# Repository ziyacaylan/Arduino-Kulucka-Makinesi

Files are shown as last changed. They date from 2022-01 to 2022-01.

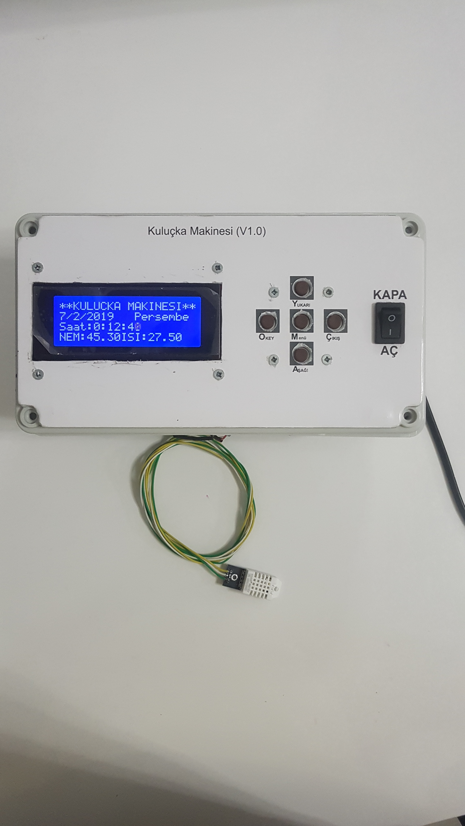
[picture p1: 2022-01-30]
20190207_001548.jpg

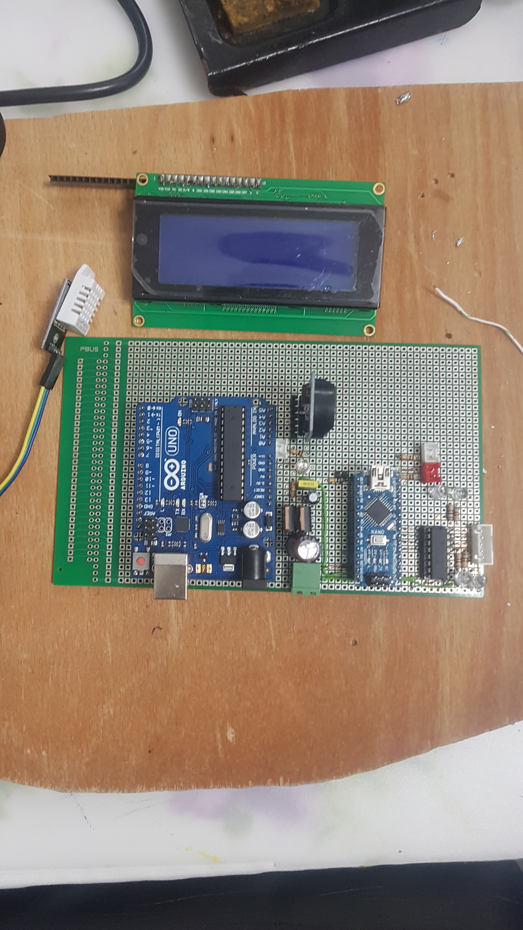
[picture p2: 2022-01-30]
20190119_183852.jpg

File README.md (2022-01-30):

# Arduino-Kulucka-Makinesi
Arduino Uno ile yapilmistir.

Kulucka makinesi 24 lü viyol e sahip, 
program arduino uno kullanılarak hazırlanmıştır. 
Tamamen elimdeki malzemelerden kullanarak tasarladım. 
Sadece saat modili ve sensörleri temin etmiştim. 
Program incelenerek geliştirilebilir yada aynı şekilde kullanılabilir. 
Denemsi yapılmıştır ve başarılı bir civciv çıkımı sağlanmıştır.
Viyol kontraplak kullanılarak yapılmıştır. 
Solidworks çizimleri dosya içerisindedir.
Arduino programı geliştirilebilir.
Viyol motoru olarak elimde step motyor elduğundan ben step motor kullandım ve step motoru ULN2003 entegresi ile sürdüm.
Entegreyide arduino nano vardı fazla elimde onunla programlayıp sürdüm. Arduino uno dan tetik alıp nanoyu sürdüm. 
Sizler elinizdeki malzemelere göre projeyi düzenleyebilirsiniz.

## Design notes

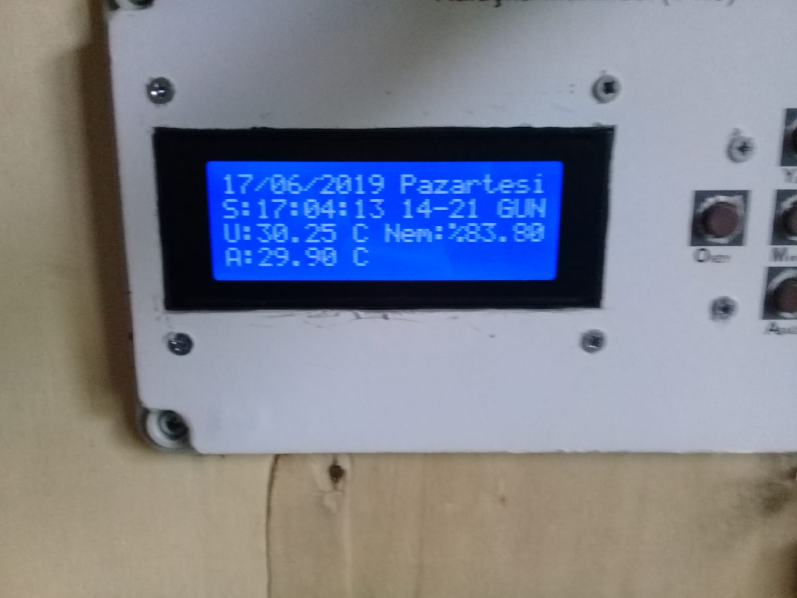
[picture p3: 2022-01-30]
IMG-20190617-WA0002.jpg

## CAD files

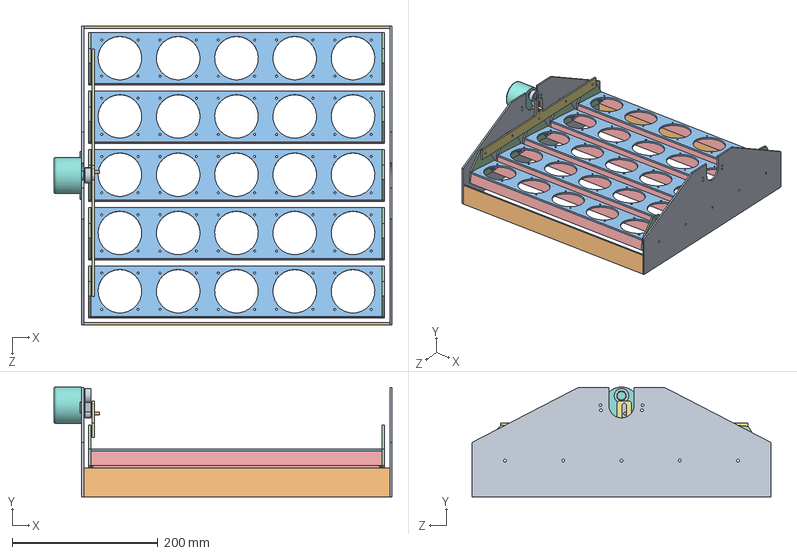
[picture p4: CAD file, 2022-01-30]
Viyol_Solid Design/NEW/montaj.SLDASM
464.0 x 151.0 x 410.0 mm
Kasa_on_arka x 2
Kasa_yan x 2
yiyol x 5
viyol_on_arka x 10
viyol_yan x 10
viyol_destek x 20
Viyol_mafsal
Motor
motor_segman
vida

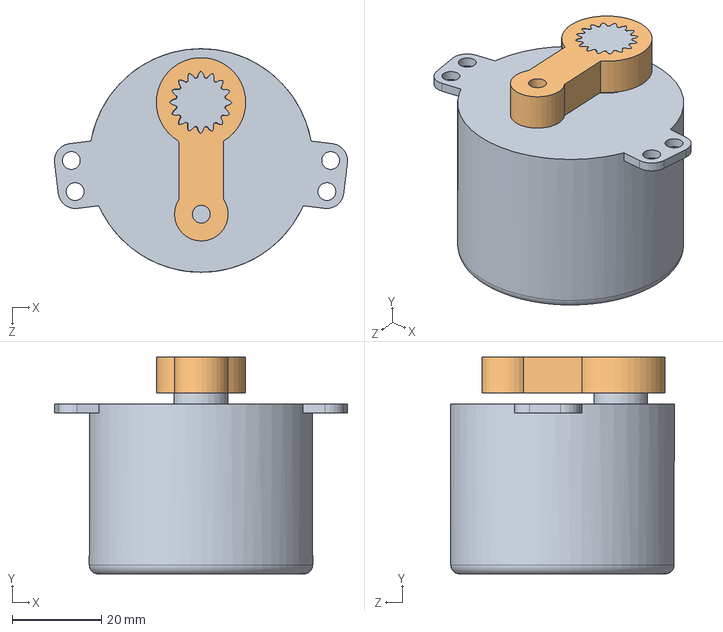
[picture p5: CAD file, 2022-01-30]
Viyol_Solid Design/NEW/motor_montaj.SLDASM
65.5 x 48.5 x 50.0 mm
Motor
motor_segman

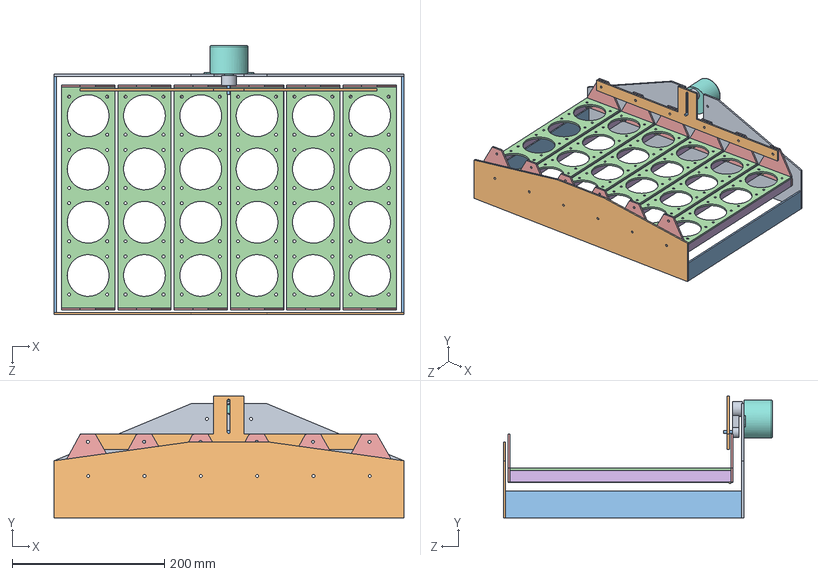
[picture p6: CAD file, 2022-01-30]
Viyol_Solid Design/6lı/montaj.SLDASM
460.0 x 160.0 x 354.0 mm
Kasa_on
Viyol_kasa_arka
Kasa_yanlar x 2
viyol x 6
viyol_on_arka x 12
viyol_yanlar x 12
viyol_destek x 24
Motor
motor_segman
vida

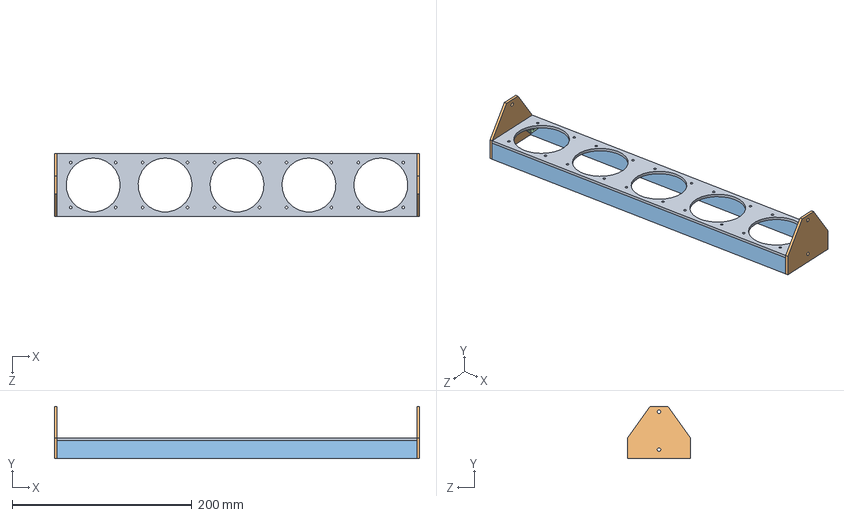
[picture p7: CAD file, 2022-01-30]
Viyol_Solid Design/NEW/viyol.SLDASM
406.0 x 58.0 x 70.0 mm
yiyol
viyol_on_arka x 2
viyol_yan x 2
viyol_destek x 4

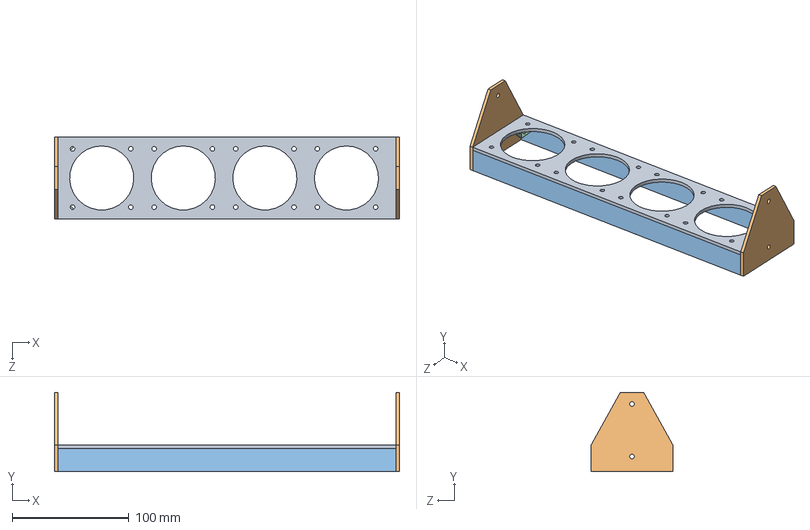
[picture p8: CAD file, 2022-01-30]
Viyol_Solid Design/6lı/viyol_montaj.SLDASM
296.0 x 68.0 x 70.0 mm
viyol
viyol_on_arka x 2
viyol_yanlar x 2
viyol_destek x 4

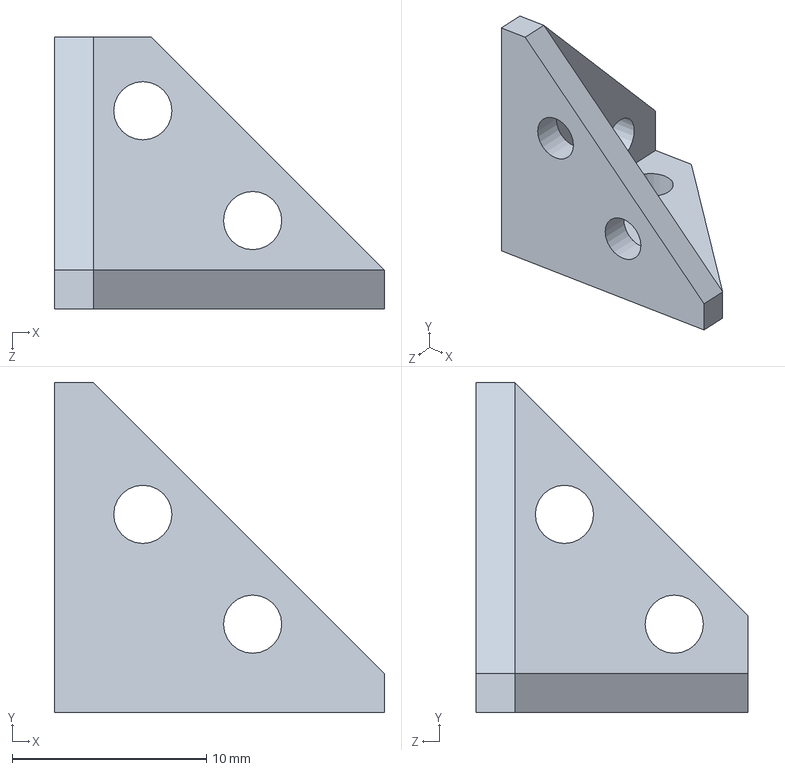
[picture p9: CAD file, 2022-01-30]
Viyol_Solid Design/6lı/viyol_destek.SLDPRT
17.0 x 17.0 x 14.0 mm

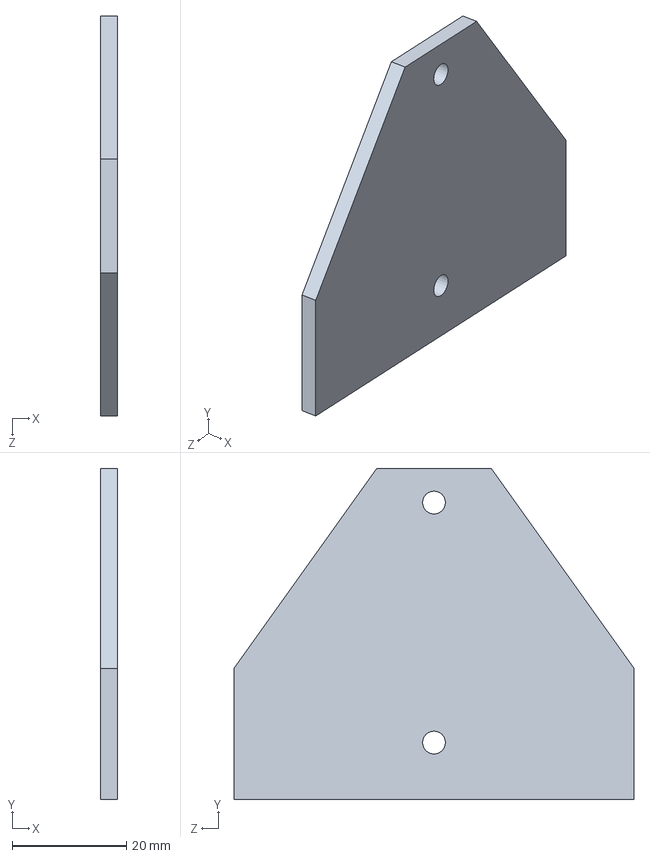
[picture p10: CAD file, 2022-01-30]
Viyol_Solid Design/NEW/viyol_on_arka.SLDPRT
3.00 x 58.0 x 70.0 mm

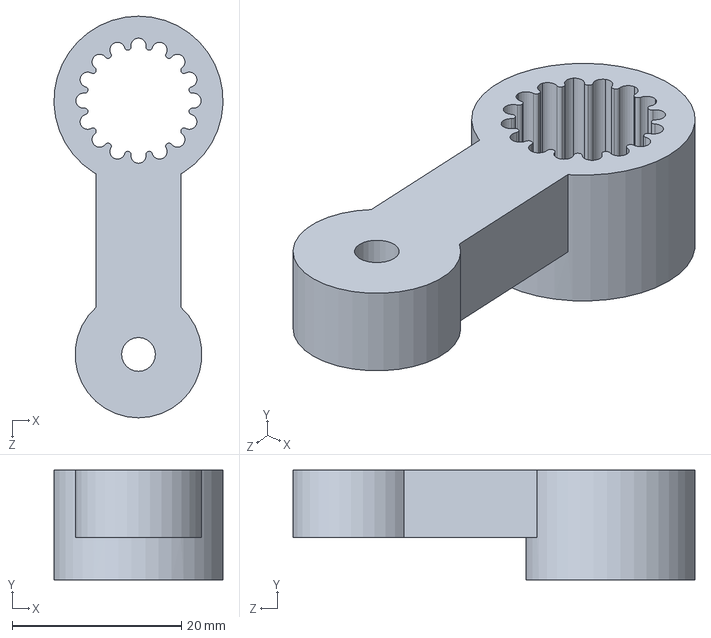
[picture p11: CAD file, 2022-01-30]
Viyol_Solid Design/6lı/motor_segman.SLDPRT
20.0 x 13.0 x 47.5 mm

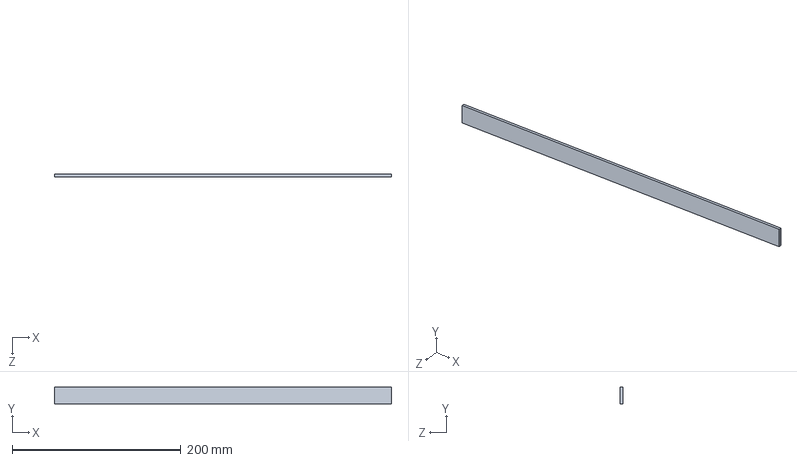
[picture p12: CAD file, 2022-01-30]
Viyol_Solid Design/NEW/viyol_yan.SLDPRT
400.0 x 20.0 x 3.00 mm

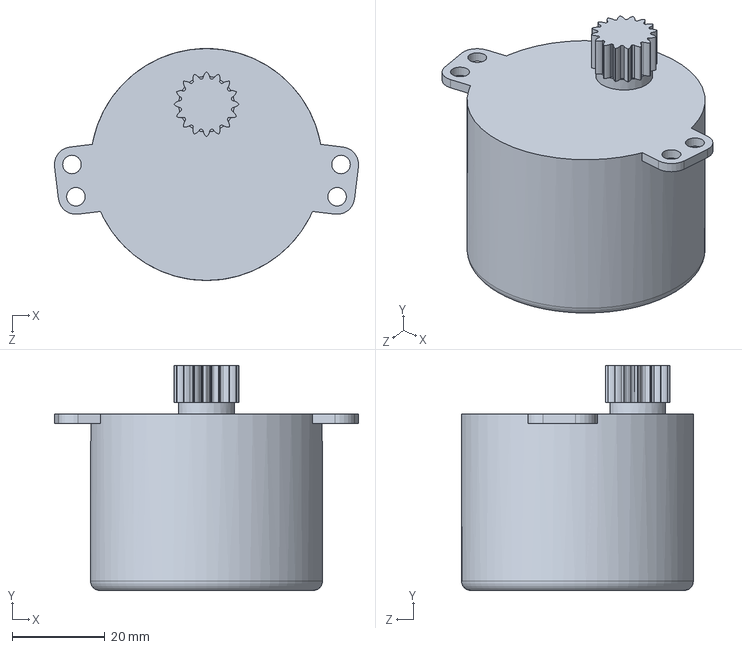
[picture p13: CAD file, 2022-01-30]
Viyol_Solid Design/6lı/Motor.SLDPRT
65.5 x 48.5 x 50.0 mm

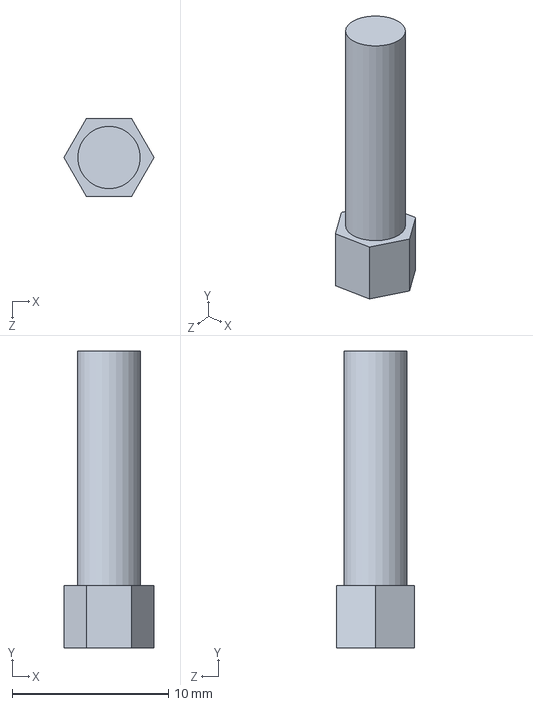
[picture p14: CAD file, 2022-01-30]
Viyol_Solid Design/NEW/vida.SLDPRT
5.77 x 19.0 x 5.00 mm

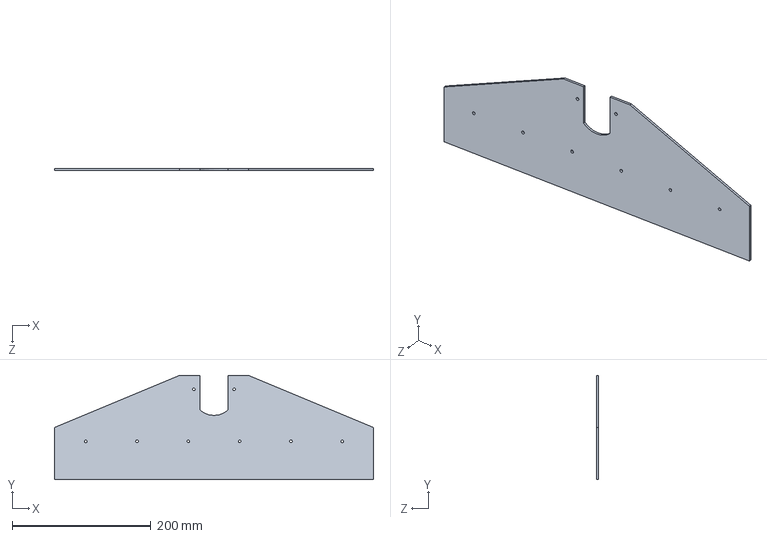
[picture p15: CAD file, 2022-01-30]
Viyol_Solid Design/6lı/Kasa_on.SLDPRT
460.0 x 150.0 x 3.00 mm

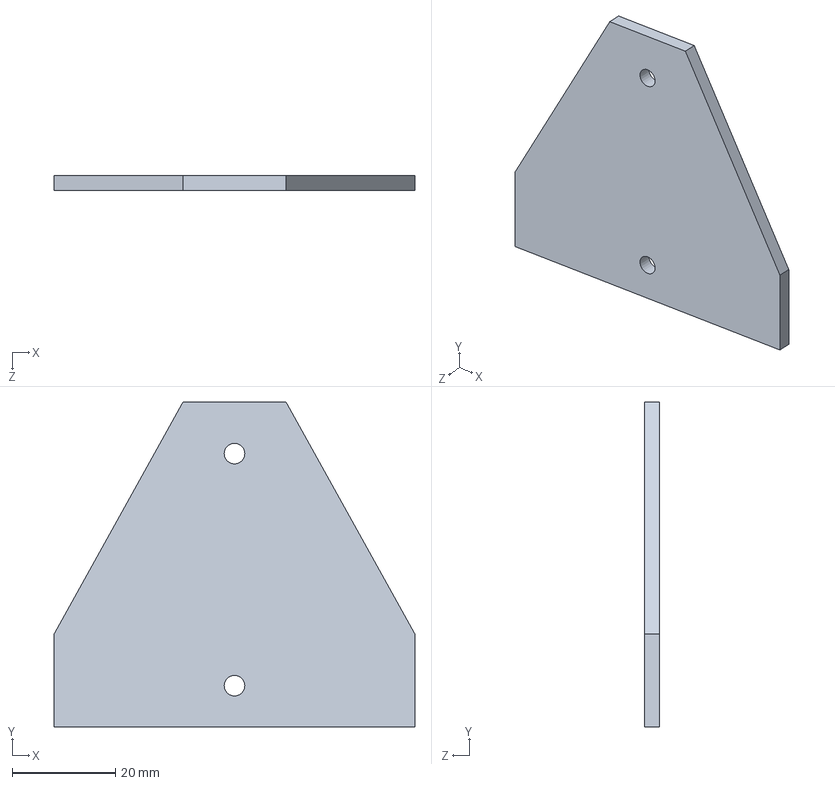
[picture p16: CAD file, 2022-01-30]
Viyol_Solid Design/6lı/viyol_on_arka.SLDPRT
70.0 x 63.0 x 3.00 mm

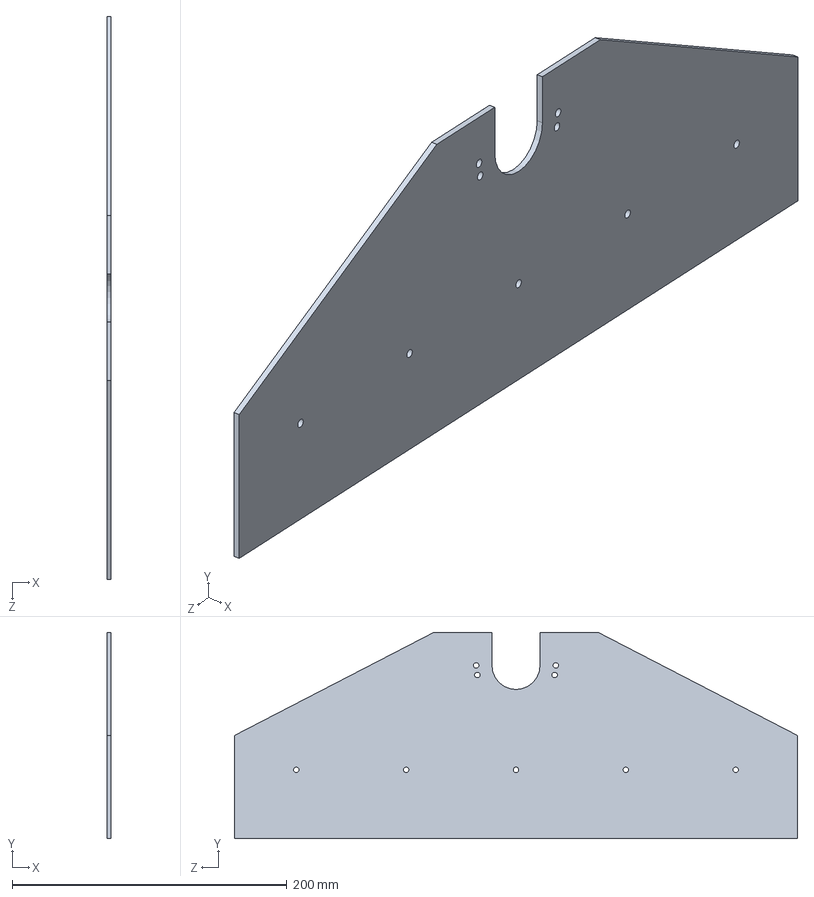
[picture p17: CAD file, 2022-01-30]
Viyol_Solid Design/NEW/Kasa_on_arka.SLDPRT
3.00 x 150.0 x 410.0 mm

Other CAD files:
Viyol_Solid Design/6lı/viyol.SLDPRT
Viyol_Solid Design/NEW/Viyol_mafsal.SLDPRT
Viyol_Solid Design/6lı/Kasa_yanlar.SLDPRT
Viyol_Solid Design/6lı/Sensor_tutucu.SLDPRT
Viyol_Solid Design/6lı/Sensor_tutucu.STL
Viyol_Solid Design/6lı/Viyol_kasa_arka.SLDPRT
Viyol_Solid Design/6lı/motor_segman.STL
Viyol_Solid Design/6lı/viyol_destek.STL
Viyol_Solid Design/6lı/viyol_mafsal.SLDPRT
Viyol_Solid Design/6lı/viyol_yanlar.SLDPRT
Viyol_Solid Design/NEW/Kasa_yan.SLDPRT
Viyol_Solid Design/NEW/motor_segman.SLDPRT
Viyol_Solid Design/NEW/viyol_destek.SLDPRT
Viyol_Solid Design/NEW/yiyol.SLDPRT

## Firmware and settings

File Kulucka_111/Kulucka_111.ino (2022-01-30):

/* KULUÇKA MAKİNESİ ******************<<<<<<<<<<<<<< CİVCİV CIKARAN 3000  >>>>>>>*********************************************
    Programı Yazan  :Ziya ÇAYLAN
    Tarih           :18.02.2019

    BAĞLANTILAR

      LCDPin Numaraları         : Pin 7,Pin 6,Pin 5,Pin 4,Pin 3,Pin 2 (rs, e, d4, d5, d6, d7)
      DHT22 Nem + Isıs Sensörü  : Pin 12
      DS18B20 Isı Sensörü       : Pin 9
      Botun Girişi              : A0
      RTC Saat (DS3231)         : SDA Pin A4, SCL Pin A5

      //ÇIKIŞLAR

      Viyol Motor     : Pin 8
      Isıtıcı         : Pin 11
      Nem + Fan       : Pin 10
      Soğutma Fan     : Pin 13
*/

/* YAZILIMIN ÇALIŞMA ALGORİTMASI************************************

    Arduino ilk açıldığında EEPROM ekonur ve kayıtlı bilgilere göre eğer bir program sürüyor ise kaldığı yerden devam eder. Yoksa ana ekrana temel bilgilerin basar.
    Menü tuşuna basılırsa ana menüye girilir.


*/
#include <OneWire.h>
#include <DallasTemperature.h>
#include <Wire.h>
#include <LiquidCrystal.h>
#include "RTClib.h"
#include <DHT.h>;
// Makina acip kapatildiginda bilgileri hafızada tutmak icin kullanılan EEPROM'a kayıt yapabilmek icin kullanılan Kutuphane
#include <EEPROM.h>
// Arduino kilitlenirse bunu tespit edip Arduino'yu tekrardan baslatacak olan Kutuphane
//#include <avr/wdt.h>

#define ONE_WIRE_BUS 9   // DS18B20 Sensör Bağlantını belirttik. Data ile 5V DC arasına 4,7K direnç bağlıyoruz.
#define DHTPIN 12        // DHT11PIN olarak Dijital 3 belirtiyorum belirliyoruz.
#define DHTTYPE DHT22   // DHT 22 Sensoru Kullandigimizi belirtiyoruz.

DHT dht(DHTPIN, DHTTYPE);
OneWire oneWire(ONE_WIRE_BUS);
DallasTemperature sensors(&oneWire);

//Değişkenler Listesi
//int chk;
float derece = 0;                     // İstenen Sıcaklık Derecesi                                                    (EEPROM)
float derece_olcum_1;                   // Olculen Sicaklık Derecesi
float derece_olcum_2;                   // Olculen Sicaklık Derecesi DS18B20 den ölçülen Sıcaklık
int bas_derece = 0;;                     // Isı ilk açıldığında max dereceye çıkarmak için kullanılacak
float kalibre_derece = 0.1;
float cikim_derece = 0;                // Çıkım evresindeki gereken sıcaklık
int cikim_nem = 0;                    //Çıkım evresindeki gereken Nem
//float derece_kalibre = 0;             // İsi donanımında kalibrasyon yapmak icin (Fabrika Reset Sonrasi 0 Olur)       (EEPROM)        (-5.00 ... 0 .. +5.00 )
long dereceolcmesec = 0;              // Her Saniyede 1 Kere sicaklik olcumu yapmak icin gerekli TEMP degisken
float derece_max;                     // Sıcaklık yukseldigi takdirde en yuksek sicaklıgı ekranda gostermek icin
int nem = 0 ;                         // Istenen Nem Değeri                                                           (EEPROM)
float nem_olcum;                      // Olculen Nem Degeri
//int dondurme_saniye = 0;              // Viyollerin Kac Saniye Dondurulecegini tutan degisken                         (EEPROM)       (1 - 15 Sn)
int dondurme_zaman = 0;               // Viyollerin Kac Dakikada bir dondurulecegini tutan degisken                   (EEPROM)       (60 - 120 - 180 240 Dk)
int sogutma_suresi = 0;               // Günde 1 defa yumurta dinlendirme işlem süresi                                (EEPROM)       (0 - 60 - 120 Dk)
int kulucka_suresi = 21;              // Kulucka Suresi Gun olarak                                                    (EEPROM)       (1 - 45 Gun)
long kulucka_suresi_baslangic = 0;    // Kulucka baslangic tarihi Unixtimestamp olarak tutuluyor                      (EEPROM)
long kalan_gun = 0;  // Ekranda kalan gunu gostermek icin
int uretim_aktif = 0; // mode R de üretim başladı ise 1 olur diğer durumlarda değeri 0 olacak.
long  k_gunu = 0;    // Kuluçkanın kaçıncı günde olduğunu gösteriyor

int siradaki_dondurme_zamani = -1;    // Bir sonraki dondurme zamanını hesaplayıp tutar. Saat olarak (14:45:55 ise 14 tutar )
int son_dondurme_zamani = -1;         // Aynı saat icinde iki kere dondurmesin diye son Dondurme Zamanını tutar Saat olarak (14:45:55 ise 14 tutar )
long cevirmeMillis = 0;               // Cevirme Baslangic suresi ms olarak tutulur. Suanki ms > cevirme ms + (dondurme_saniye * 1000) ise dondurme kapatilir.
char mode = 'S';                      // Menuler icin yardimci degisken N = Normal Mode   R = Calis   M = Manuel Çalışma Modu  Mode S = Setup
int menu = 0;                         // Ana menu icin yardimci degisken  0 => Ayarlama Menusu 1=> Saat Ayarlama 2=> Fabrika Ayarları 3=>Isı Kalibarasyon 4=>Yeni Kulucka Girisi 5=>Cikis
int saat_oku = 0;
// Saat Ayarlama icin gerekli gecici degiskenler
//int saat_menu = 1;
int zaman_yardim = 0; //zaman ayarı yaparken menüler arası geçiş yapabilmek için kullanılan değişken
int temp_tarih = 0;
int temp_gun = 0;
int temp_ay = 0;
int temp_yil = 0;
int temp_saat = 0;
int temp_dakika = 0;
int temp_saniye = 0;
int c_ekran = 0;
int menu_sayac = 0;
int uretim_devam = 0;
int sogutma_sayac = 0;                // Calısır iken sogutma menüsüne girmek icin
int viyol_sayac = 0;                  // Calışır iken viyol cvirme menüsüne girmkicin
int calisma_cikis_sayac = 0;         // Çalışma modundan (mode 'R') çıkmak için kullanılacak sayaç

//char ayar_duzenle = 'H';              // Menuler icin yardimci degisken H = Baslangic Tarih Sıfırlar E = Tarih Sabit Kalır
char *menuler [11] = {"1-Uretime BASLA", "2-Manuel Kontrol", "3-Ayarlar", "4-Cikis", "1-Tarih Ayari", "2-Sicaklik Ayari", "3-Nem Ayari", "4-Kulucka Gunu", "5-Baslangic Tarihi", "6-Cikim Sicaklik", "7-Cikim Nemi"};

//****************ALT MENÜLER****************************
// Menu 5 -> Tarih Ayari
// Menu 6 -> Sicaklık Ayari
// Menu 7 -> Nem Ayari
// Menu 8 -> Kulucka Gun Ayari
// Menu 9 -> Baslangic Tarihi
// Menu 10 -> Cikim Sicakligi
// Menu 11 -> Cikim Nemi
//****************ALT MENÜLER****************************
////////////////////////////////////////////////////////////////////////////////
// Relaylar
#define RELAY_ISI  11                  // Isıtıcı Pini Tanımlandı
#define RELAY_NEM  10                  // Nem Nozzle ve Fan Açma/Kapama Pini Tanımlandı
#define RELAY_SOGUTMA  13                // Soğutma Fanları Pini Tanımlandı
#define VIYOL_MOTOR  8                 // Viyol Motor Sürücü Pini Tanımlandı (Röle ye Bağlı Değil)
////////////////////////////////////////////////////////////////////////////////

// Buton Tanımlama
#define buton A0

DateTime now;
char daysOfTheWeek[7][12] = {"Pazar", "Pazartesi", "Sali", "Carsamba", "Persembe", "Cuma", "Cumartesi"};

RTC_DS3231 rtc;
LiquidCrystal lcd(7, 6, 5, 4, 3, 2); // (rs, e, d4, d5, d6, d7)) LCD Bağlantıları Belirtildi

void showDate(void);
void showTime(void);
void showDay(void);
void tarih_saat_ayarla(void);
void setup() {
  // Kilitlenme
  //  wdt_enable(WDTO_4S);                 // Kilitlenme Olursa diye 4 Saniyelik bir sure tanımlıyoruz ve fonk. baslatiyoruz. Eğer program 4 sn icinde tekrar aynı yere gelmez ise Arduino Reset atacak kendine

  // Relaylar Ayarlandı
  pinMode(RELAY_ISI, OUTPUT);
  pinMode(RELAY_NEM, OUTPUT);
  pinMode(RELAY_SOGUTMA, OUTPUT);
  pinMode(VIYOL_MOTOR, OUTPUT);

  // digitalWrite(RELAY_ISI, HIGH);
  // digitalWrite(RELAY_NEM, HIGH);
  //  digitalWrite(RELAY_SOGUTMA, HIGH);
  // digitalWrite(VIYOL_MOTOR, HIGH);

  // ButonTanımlama
  pinMode(buton, INPUT);

  lcd.begin(20, 4);  // LCD Başlatıldı
  lcd.clear();
  dht.begin();       // DHT22 Başlatıldı
  sensors.begin();   // DS18B20 Isı Sensörü Başlatıldı
  Serial.begin(9600);
  // Saat Başlatılıyor.....
  if (! rtc.begin())
  {
    Serial.println("Couldn't find RTC Module");
    while (1);
  }
  // rtc.adjust(DateTime(2019, 2, 28, 18, 0, 0));
  if (rtc.lostPower())
  {
    Serial.println("RTC lost power, lets set the time!");
    rtc.adjust(DateTime(F(__DATE__), F(__TIME__)));
    // This line sets the RTC with an explicit date & time, for example to set
    // January 21, 2014 at 3am you would call:
    //  rtc.adjust(DateTime(2014, 1, 21, 3, 0, 0));
  }
  //    for (int i = 0 ; i < EEPROM.length() ; i++)
  //    {
  //      EEPROM.write(i, 0);
  //    }
  mode =  EEPROM.read(16);   // Calisma Modunu EEPROMdan okuyoruz
  //mode = 'N';
  if (mode == 0)
  {
    // Mode yok ise Direkt ayarlama Menusune Gidiyoruz.
    mode = 'N';
    EEPROM.write(16, mode);
  }

  // Eger Mod calisma modunda ise EEPROMdan gerekli bilgileri sadece 1 kereye mahsus okuyoruz.
  if (mode == 'R' || mode == 'M')
  {
    //derece =  EEPROM.read(20);
    EEPROM_readAnything(20, derece);
    EEPROM_readAnything(64, cikim_derece);
    cikim_nem = EEPROM.read(74);
    nem = EEPROM.read(24);
    //    dondurme_saniye = EEPROM.read(28);
    dondurme_zaman = EEPROM.read(32);
    sogutma_suresi = EEPROM.read(36);
    kulucka_suresi = EEPROM.read(40);
    //Bitis timestamp okuyoruz
    EEPROM_readAnything(44, kulucka_suresi_baslangic);
    //Kalibrasyon Okuma
    //  EEPROM_readAnything(54, derece_kalibre);
  }
  //bas_derece = 0;
}

void loop()
{
  //wdt_reset();      // Kilitlenme İcin Gerekli Fonksiyonu Cagiriyoruz. Eğer 4 sn icinde program tekrar bu satıra gelmez ise Reset atıyor kendine
  //mode = 'N';
  Serial.println(mode);
  //*********Mode S Ana Menü **********************************
  if (mode == 'S')
  {
    // lcd.clear();
    // Ana Menü
    // Menu 1 -> Uretime BASLA
    // Menu 2 -> Manuel Kontrol
    // Menu 3 -> Ayarlar
    // Menu 4 -> Cikis
    //****************ANA MENÜLER****************************

    int buton_deger = analogRead(buton);
    byte basilan_buton = buton_bul(buton_deger);
    Serial.print(buton_deger);
    Serial.print(basilan_buton);

    if (basilan_buton == 4)
    {
      menu = menu + 1;
      delay(100);
    }
    else if (basilan_buton == 1)
    {
      menu = menu - 1;
      delay(100);
    }
    else if (basilan_buton == 3)
    {
      if (uretim_devam != 1)
      {
        lcd.noBlink();
        lcd.clear();
        mode = 'N';
      }
      else
      {
        lcd.noBlink();
        lcd.clear();
        mode = 'R';
      }
    }
    if (menu < 1) {
      menu = 4;
    }
    if (menu > 4) {
      menu = 1;
    }
    Serial.println(menu);
    // delay(200);
    // LCD DE Menü Listeleniyor
    //    lcd.setCursor(6, 0);
    //    lcd.print("ANA MENU");

    if (menu == 1)
    {
      lcd.setCursor(6, 0);
      lcd.print("ANA MENU");
      lcd.setCursor(0, 1);
      lcd.print(menuler[0]);//Üretime Başla
      lcd.setCursor(0, 2);
      lcd.print(menuler[1]);//Manuel Kontrol
      lcd.setCursor(0, 3);
      lcd.print(menuler[2]);//Ayarlar
      lcd.setCursor(2, 1);
      lcd.blink();
      delay(50);
      //delay(2000);
      if (basilan_buton == 3 )
      {
        lcd.noBlink();
        lcd.clear();
        mode = 'N';
        delay(150);
      }
      else if (basilan_buton == 5)
      {
        lcd.noBlink();
        lcd.clear();
        uretim_aktif = 1;
        mode = 'C';
      }
    }
    if (menu == 2)
    {
      lcd.clear();
      lcd.setCursor(6, 0);
      lcd.print("ANA MENU");
      lcd.noBlink();
      lcd.setCursor(0, 1);
      lcd.print(menuler[0]);//Üretime Başla
      lcd.setCursor(0, 2);
      lcd.print(menuler[1]);//Manuel Kontrol
      lcd.setCursor(0, 3);
      lcd.print(menuler[2]);//Ayarlar
      lcd.setCursor(2, 2);
      lcd.blink();
      delay(50);
      if (basilan_buton == 3 )
      {
        lcd.noBlink();
        lcd.clear();
        mode = 'N';
      }
      else if (basilan_buton == 5)
      {
        lcd.noBlink();
        lcd.clear();
        mode = 'P';
      }
    }
    if (menu == 3)
    {
      lcd.clear();
      lcd.setCursor(6, 0);
      lcd.print("ANA MENU");
      lcd.noBlink();
      lcd.setCursor(0, 1);
      lcd.print(menuler[0]);//Üretime Başla
      lcd.setCursor(0, 2);
      lcd.print(menuler[1]);//Manuel Kontrol
      lcd.setCursor(0, 3);
      lcd.print(menuler[2]);//Ayarlar
      lcd.setCursor(2, 3);
      lcd.blink();
      delay(50);
      if (basilan_buton == 3 )
      {
        lcd.noBlink();
        lcd.clear();
        mode = 'N';
      }
      else if (basilan_buton == 5)
      {
        lcd.noBlink();
        lcd.clear();
        mode = 'A';
        menu = 5;
      }
    }
    if (menu == 4)
    {
      //lcd.clear();
      lcd.setCursor(6, 0);
      lcd.print("ANA MENU");
      lcd.noBlink();
      lcd.setCursor(0, 1);
      lcd.print(menuler[1]);//Manuel Kontrol
      lcd.setCursor(0, 2);
      lcd.print(menuler[2]);//Ayarlar
      lcd.setCursor(0, 3);
      lcd.print(menuler[3]);//Çıkış
      lcd.setCursor(2, 3);
      lcd.blink();
      delay(50);
      //      if (basilan_buton == 5 || basilan_buton == 3 )
      //      {
      //        lcd.noBlink();
      //        lcd.clear();
      //        mode = 'N';
      //      }
    }
  }
  //*********Mode N Normal Mod Sadece Ana ekran**********************************
  if (mode == 'N')
  {
    Serial.print("Mode=");
    Serial.println(mode);
    DateTime now = rtc.now();
    nem_olcum = dht.readHumidity();
    derece_olcum_1 = dht.readTemperature();
    derece_olcum_2 = getTemp();
    showDate();
    showDay();
    showTime();
    lcd.setCursor(0, 2);
    lcd.print("A:");
    lcd.print(derece_olcum_1);
    lcd.print(" C");
    lcd.setCursor(10, 2);
    lcd.print("U:");
    lcd.print(derece_olcum_2);
    lcd.print(" C");
    lcd.setCursor(0, 3);
    lcd.print("Nem: %");
    lcd.print(nem_olcum);

    int buton_deger = analogRead(buton);
    Serial.print("buton_deger=");
    Serial.println(buton_deger);
    byte basilan_buton = buton_bul(buton_deger);
    Serial.print("Basılan Buton=");
    Serial.println(basilan_buton);

    if (basilan_buton == 2)
    {
      mode = 'S';
      menu = 1;
      lcd.clear();
    }

  }
  //*******************************Maniel Çalışma Aktif oluyor*******************************
  if (mode == 'P')
  {
    int buton_deger = analogRead(buton);
    byte basilan_buton = buton_bul(buton_deger);

    lcd.setCursor(2, 0);
    lcd.print("MANUEL CALISMA ");
    lcd.setCursor(2, 1);
    lcd.print("AKTIF OLSUN MU");

    if (basilan_buton == 3)
    {
      mode = 'S';
      lcd.clear();
      delay(150);
    }
    else if (basilan_buton == 5)
    {
      mode = 'M';
      lcd.clear();
      EEPROM.write(16, mode);
      delay(150);
    }
  }
  if (mode == 'A')
  {
    //****************ALT MENÜLER****************************
    // Menu 5 -> Tarih Ayari      (mode 'Z')
    // Menu 6 -> Sicaklık Ayari   (mode 'D')
    // Menu 7 -> Nem Ayari         (mode 'B')
    // Menu 8 -> Kulucka Gun Ayari (mode 'K')
    // Menu 9 -> Baslangic Tarihi  (mode 'C')
    // Menu 10 -> Cikim Sicakligi  (mode 'E')
    // Menu 11 -> Cikim Nemi       (mode 'F')
    //****************ALT MENÜLER****************************

    int buton_deger = analogRead(buton);
    byte basilan_buton = buton_bul(buton_deger);
    delay(150);
    Serial.print(mode);
    Serial.println(basilan_buton);
    Serial.print(menu);
    if (basilan_buton == 4)
    {
      menu = menu + 1;
    }
    else if (basilan_buton == 1)
    {
      menu = menu - 1;
    }
    if (menu < 5) {
      menu = 11;
    }
    if (menu > 11) {
      menu = 5;
    }
    if (menu == 5)  ///////Tarih Ayarı******************************************************
    {
      //+lcd.clear();
      lcd.setCursor(6, 0);
      lcd.print("AYARLAR");
      lcd.setCursor(0, 1);
      lcd.print(menuler[4]);//Tarih Ayari
      lcd.setCursor(0, 2);
      lcd.print(menuler[5]);//Sicaklik Ayari
      lcd.setCursor(0, 3);
      lcd.print(menuler[6]);//Nem Ayari
      lcd.setCursor(2, 1);
      lcd.blink();
      delay(150);
      if (basilan_buton == 3 )
      {
        lcd.noBlink();
        lcd.clear();
        mode = 'A';
      }
      if (basilan_buton == 5)
      {
        Serial.print("deneme saate git");
        mode = 'Z';
        Serial.print(mode);
      }
    }
    if (menu == 6) ///////Sıcaklık Ayarı******************************************************
    {
      //lcd.clear();
      //lcd.setCursor(6, 0);
      // lcd.print("AYARLAR");
      lcd.setCursor(0, 1);
      lcd.print(menuler[4]);//Tarih Ayari
      lcd.setCursor(0, 2);
      lcd.print(menuler[5]);//Sicaklik Ayari
      lcd.setCursor(0, 3);
      lcd.print(menuler[6]);//Nem Ayari
      lcd.setCursor(2, 2);
      lcd.blink();
      delay(150);
      if (basilan_buton == 3 )
      {
        if (uretim_devam != 1)
        {
          lcd.noBlink();
          lcd.clear();
          mode = 'A';
        }
        else
        {
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
